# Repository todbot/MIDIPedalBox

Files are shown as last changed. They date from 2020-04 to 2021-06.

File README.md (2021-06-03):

# MIDIPedalBox

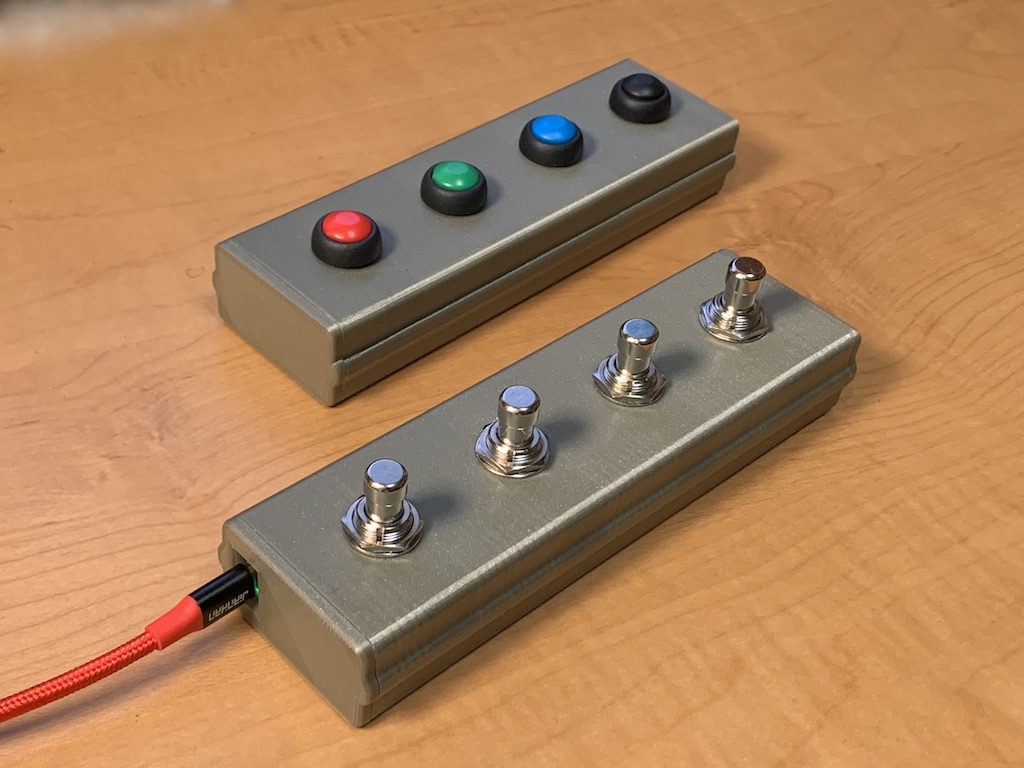
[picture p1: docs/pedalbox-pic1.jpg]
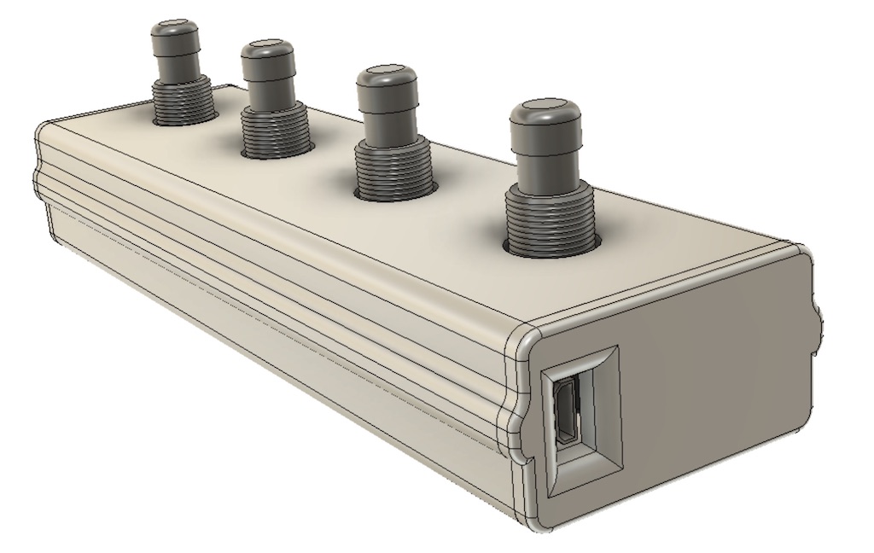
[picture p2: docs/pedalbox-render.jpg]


## Trinket M0 + CircuitPython USB MIDI Pedal Box

## Wiring  

The wiring is pretty straight-forward. A single wire goes from each button to pins 1,2,3,4 and a common ground connecting everybody.

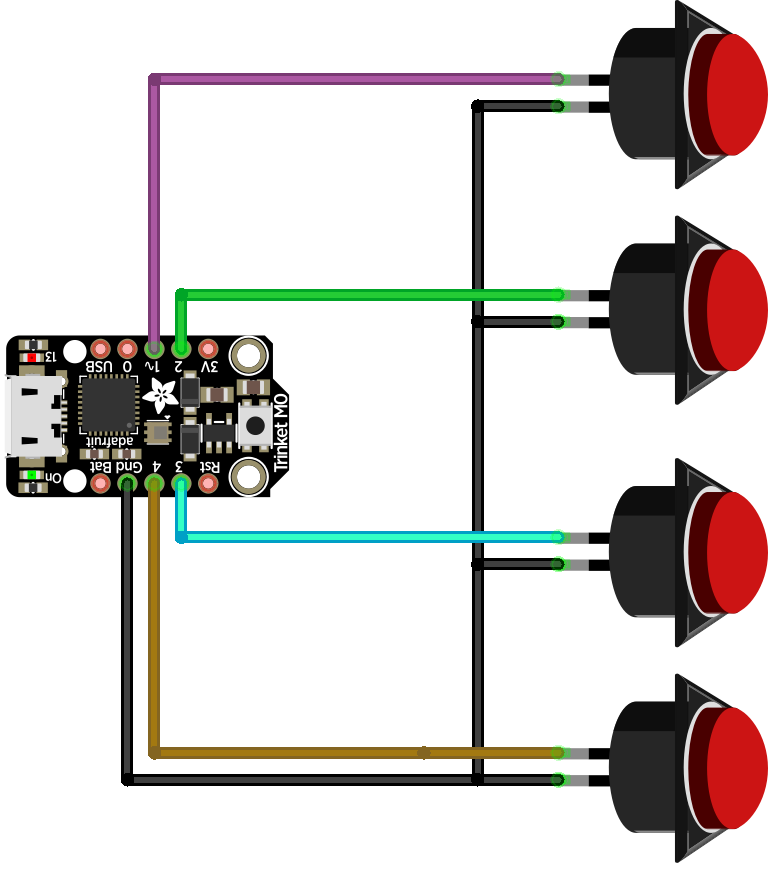
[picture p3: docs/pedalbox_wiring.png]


## Parts

The parts used for MIDIPedalBox:

- 1 - Adafruit Trinket M0
   - [Buy from Adafruit](https://www.adafruit.com/product/3500)
   - A [QT Py](https://www.adafruit.com/product/4600) or [Seeed XIAO](http://amzn.com/B08745JBRP?tag=todbotblog-20) will work too, with minor code modifications

- 4 - effects pedal switches
  - I chose these [generic momentary ones](http://amzn.com/B076V8C3LV?tag=todbotblog-20),
  but there are many to choose from and most all will work. Be sure to check dimensions to be sure!

or if you want push buttons instead of foot switches,

- 4 - 12 mm momentary buttons
  - I used [these from All Electronics](https://www.allelectronics.com/item/pb-138/spst-n.o.-pushbutton-red/1.html), but the equivalent are [available from Amazon](http://amzn.com/B07F24Y1TB?tag=todbotblog-20)

If you want to add serial MIDI out, the CAD includes a hole for a panel mount MIDI jack,
like [this one](http://amzn.com/B01GBT9RC0?tag=todbotblog-20)

_(Note: all Amazon links are affiliate links)_

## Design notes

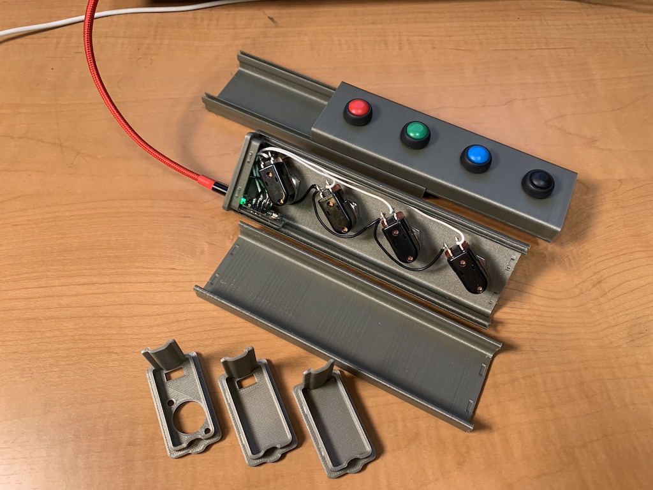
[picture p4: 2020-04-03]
docs/pedalbox-pic2.jpg

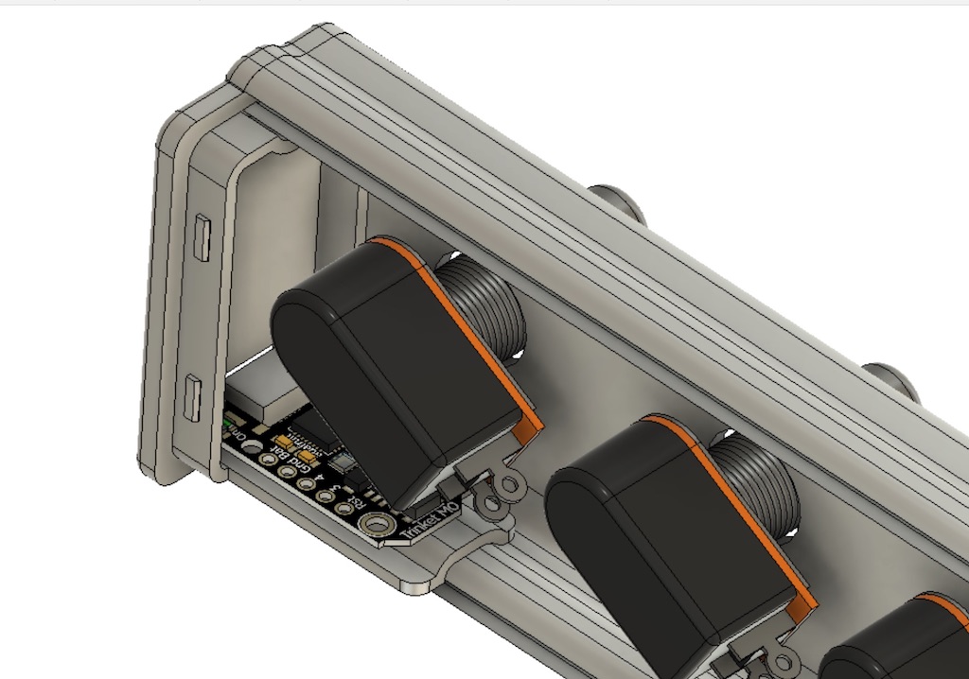
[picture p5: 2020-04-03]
docs/pedalbox-insides-render.jpg

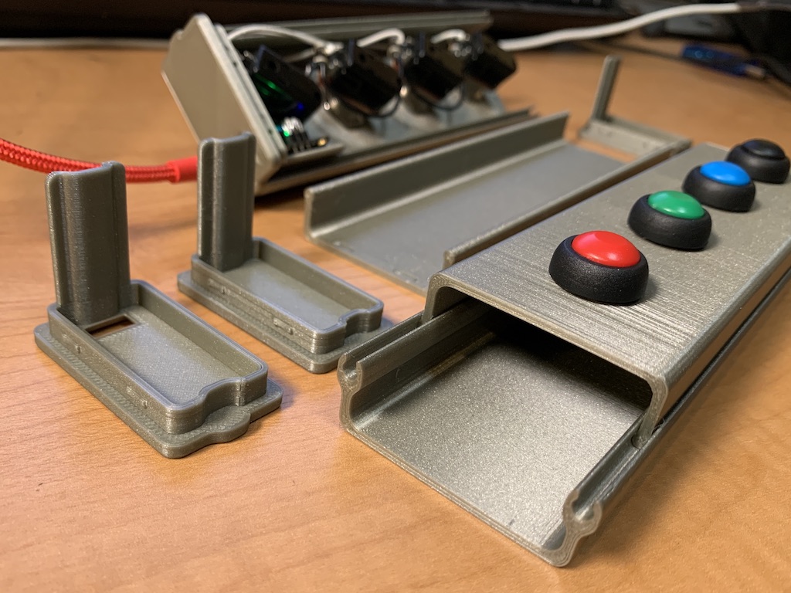
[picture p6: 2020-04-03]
docs/pedalbox-pic3.jpg

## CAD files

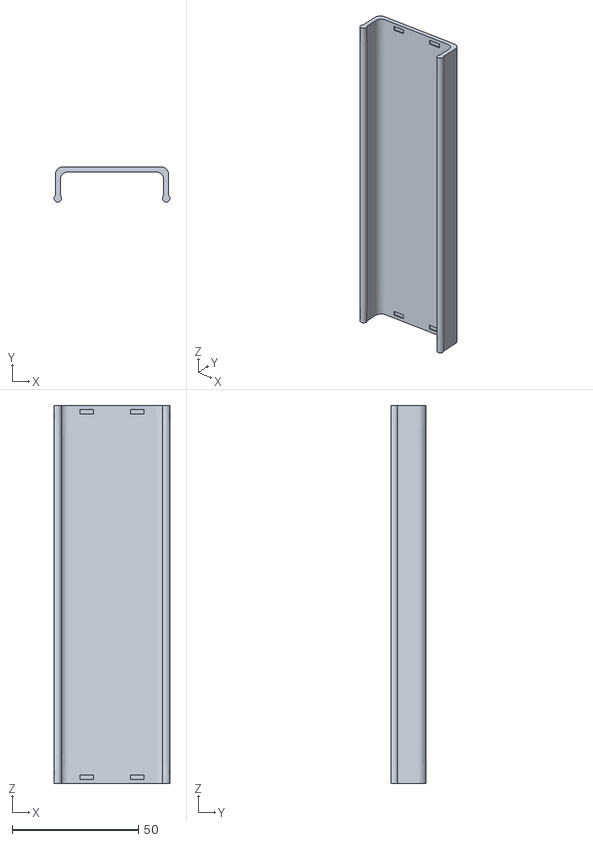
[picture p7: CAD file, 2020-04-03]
case/pedalbox-mainbot.stl
46.0 x 14.0 x 150.0

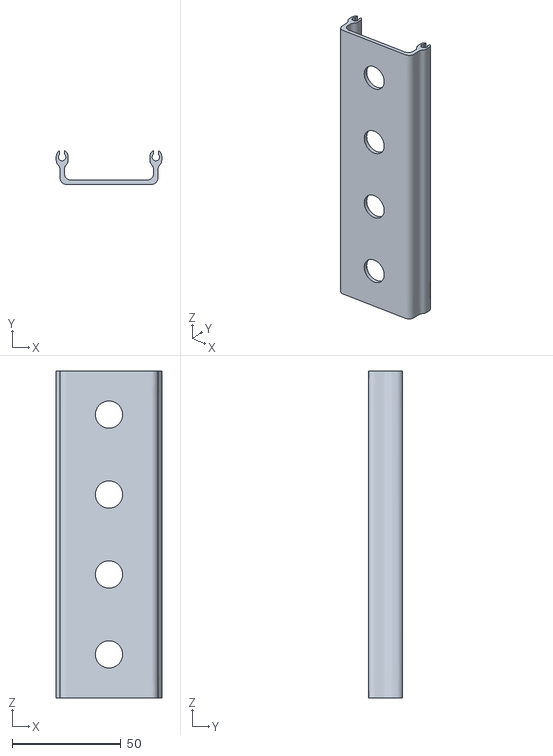
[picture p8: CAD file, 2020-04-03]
case/pedalbox-maintop.stl
48.4 x 15.5 x 150.0

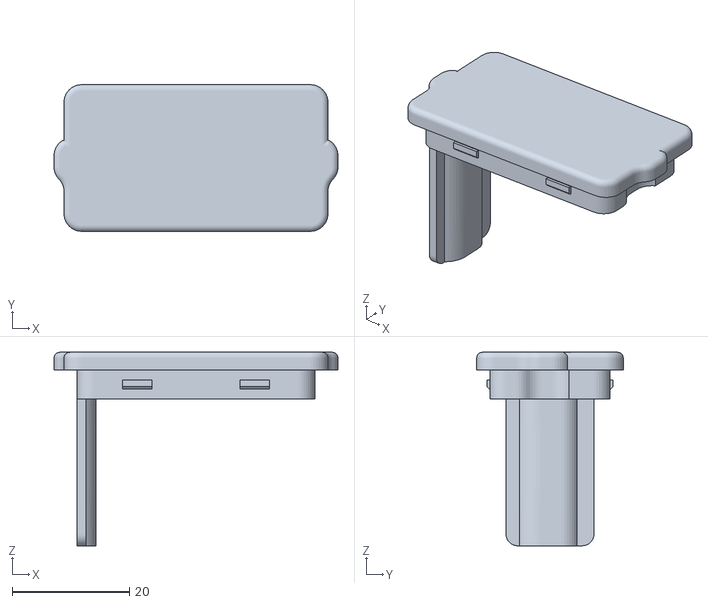
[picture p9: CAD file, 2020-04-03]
case/pedalbox-endcap_blank.stl
48.4 x 25.0 x 33.0

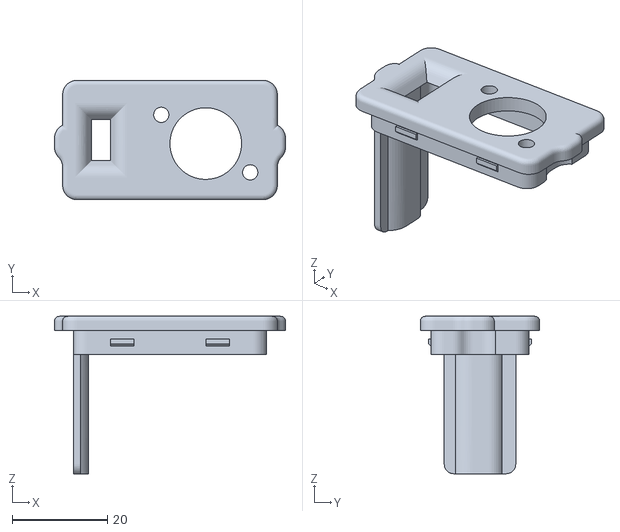
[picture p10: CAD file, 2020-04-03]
case/pedalbox-endcap_ midi.stl
48.4 x 25.0 x 33.0

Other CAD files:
case/pdealbox-endcap.stl
case/pedalbox.f3d

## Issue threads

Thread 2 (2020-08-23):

softreboot with pedalbox_keyboard.py

ericklein, 2020-08-23:
I logged an issue at https://github.com/adafruit/Adafruit_CircuitPython_Debouncer/issues/21 but wondering if you are seeing the same issue? I modified your code for debug and saw the same soft reboot I reported above after X loops with no button input.

I can remove the LED code with no change in output.
```
import time
import board
from digitalio import DigitalInOut, Direction, Pull
# import digitalio #adafruit version
# from analogio import AnalogOut, AnalogIn  #why do we need it?

import usb_hid
from adafruit_hid.keyboard import Keyboard
from adafruit_hid.keycode import Keycode
from adafruit_debouncer import Debouncer

print("imports ok")

# Your config!
# Set this to be which pins you're using, and what to do.
# For list of keycodes, see:
# https://circuitpython.readthedocs.io/projects/hid/en/latest/api.html
button_config = [
        # pin,     (Keycodes and modifier keycodes)
        [board.A1, (Keycode.SPACEBAR,) ],  # just a space
]
debouncers = []

#        [board.D2, (Keycode.A, Keycode.SHIFT, Keycode.GUI) ],# zoom mute
#        [board.D3, (Keycode.C, Keycode.CONTROL) ],
#        [board.D4, (Keycode.H, Keycode.GUI) ], # CMD-H hide

# start up the keyboardy-ness
time.sleep(1)  # Sleep for a bit to avoid a race condition on some systems
kbd = Keyboard(usb_hid.devices)

print("keyboard init ok")

# Built in red LED
led = DigitalInOut(board.D13)
led.direction = Direction.OUTPUT
button_light = DigitalInOut(board.D7)
button_light.direction = Direction.OUTPUT

print("LED setup ok")

# set up the pins and the debouncer on each pin
for (pin,*rest) in button_config:
        button = DigitalInOut(pin)
        button.direction = Direction.INPUT
        button.pull = Pull.UP
        debouncers.append( Debouncer(button) )

print("ready for main loop")

######################### MAIN LOOP ##############################
def main():
    while True:
        for i in range(len(button_config)):
            button = debouncers[i]
            button.update()

            (pin,keycodes) = button_config[i]
            print("button",i,"ready")
            if button.fell:
                print("push:",pin,"keycodes:",keycodes)
                #kbd.send(Keycode.SHIFT,Keycode.A)
                kbd.press(*keycodes)
                led.value = True
                button_light.value = True

            if button.rose:
                print("release:",pin)
                kbd.release(*keycodes)
                led.value = False
                button_light.value = False

            time.sleep(0.01)
######

# actually call main
main()
```

todbot, 2020-08-23:
interesting! I have not seen that but I've not gotten back to this project since I initially made it and I'm not sure I ever even had it running that long!

ericklein, 2020-08-23:
If you want to close this I can always open a new issue if I indeed find something.

todbot, 2020-08-24:
so I'm not seeing this on a Trinket M0 or an ItsyBitsy M4 running the `debouncer_simpletest.py`

Do you perhaps have an editor (like Mu) or other program that auto-scans serial ports, causing your board to disconnect/reconnect?

ericklein, 2020-08-24:
I’m slowly learning CP and just read that Mu can cause issues. Back to exclusive Sublime Text :) thanks for checking!

Sent via Superhuman iOS ( https://sprh.mn/?vip=me@ericklein.com )

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

Closed 2020-08-23.

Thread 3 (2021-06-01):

Recommended switches

gmeader, 2021-06-01:
What foot switch switches do you use?
Source?
Put that info in the README?

todbot, 2021-06-02:
All foot switches are pretty identical (to my non-guitarist eye), with the only real difference being momentary vs push-on/push-off.  The specific ones I purchased were these I think: https://www.amazon.com/Etopars-Guitar-Effects-Momentary-Button/dp/B076V8C3LV/

You are correct, I should add a BOM to the README. Thanks!

todbot, 2021-06-03:
thanks again!

Closed 2021-06-03.

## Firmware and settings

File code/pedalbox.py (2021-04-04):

# MIDIPedalBox -- USB and Classic MIDI output on a Trinket M0
#
# 2020-2021 @todbot / Tod E. Kurt
#
# To use:
#  - Copy this file as `code.py` in your Trinket's CIRCUITPY drive
#  - Install necessary extra libraries (see below)
#
# Extra modules needed:
# - adafruit_dotstar
# - adafruit_midi (but only "__init.mpy", "node_on.mpy", "note_off.mpy")
# - adafruit_debouncer
#
# These libraries can be installed all at once with:
#  circup install circup install adafruit_dotstar adafruit_midi adafruit_debouncer
# Get `circup` with `pip3 install circup`
#
# Classic MIDI (5-pin DIN MIDI) is on pin D0 and can be wired up as shown in
# the diagrams here:
#  https://learn.adafruit.com/classic-midi-synth-control-with-trellis-m4/midi-connections
# Specifically I've had luck with the following wiring:
#  - Trinket Gnd    ----------------------> Ring of Type-B adapter   --> MIDI pin 2
#  - Trinket 3v3    --> 47 ohm resistor --> Tip of Type-B adapter    --> MIDI pin 4
#  - Trinket Pin D0 --> 47 ohm resistor --> Sleeve of Type-B adapter --> MIDI pin 5
#

import time
import board
import busio
from digitalio import DigitalInOut, Direction, Pull
from analogio import AnalogOut, AnalogIn
import adafruit_dotstar as dotstar

import usb_midi
import adafruit_midi
from adafruit_midi.note_off         import NoteOff
from adafruit_midi.note_on          import NoteOn
from adafruit_debouncer import Debouncer

# memory is tight on Trinket, so let's clean up before we start
import gc
gc.collect()

# Your config!
# Set this to be which pins you're using, and what to do
button_config = [
		# pin,     midi press msg, midi release msg
		[board.D1, NoteOn(44,120), NoteOff(44,120) ],
		[board.D2, NoteOn(46,120), NoteOff(46,120) ],
		[board.D3, NoteOn(48,120), NoteOff(48,120) ],
		[board.D4, NoteOn(50,120), NoteOff(50,120) ],
]
debouncers = [] 

midi = adafruit_midi.MIDI(midi_out=usb_midi.ports[1], out_channel=0)
uart = busio.UART(board.D0, baudrate=31250, timeout=0.001) # initialize UART 
classic_midi = adafruit_midi.MIDI(midi_out=uart )

# One pixel connected internally!
dot = dotstar.DotStar(board.APA102_SCK, board.APA102_MOSI, 1, brightness=0.2)

# Built in red LED
led = DigitalInOut(board.D13)
led.direction = Direction.OUTPUT

# set up the pins and the debouncer on each pin
for (pin,*rest) in button_config:
		button = DigitalInOut(pin)
		button.direction = Direction.INPUT
		button.pull = Pull.UP
		debouncers.append( Debouncer(button) )
   
######################### MAIN LOOP ##############################
def main():
    doti = 0 
    while True:
        for i in range(len(button_config)):
            button = debouncers[i]
            button.update()
            
            (pin,onPress,onRelease) = button_config[i]
            
            if button.fell:
                print("push:",pin)
                midi.send(onPress)
                classic_midi.send(onPress)
                
            if button.rose:
                print("release:",pin)
                midi.send(onRelease)
                classic_midi.send(onRelease)
                
        # spin internal LED around! autoshow is on
        dot[0] = wheel(doti & 255)
        doti = (doti+1) % 256  # run from 0 to 255

######################### HELPERS ##############################

# Helper to give us a nice color swirl
def wheel(pos):
    # Input a value 0 to 255 to get a color value.
    # The colours are a transition r - g - b - back to r.
    if (pos < 0):   return [0, 0, 0]
    if (pos > 255): return [0, 0, 0]
    if (pos < 85):  return [int(pos * 3), int(255 - (pos*3)), 0]
    elif (pos < 170):
        pos -= 85
        return [int(255 - pos*3), 0, int(pos*3)]
    else:
        pos -= 170
        return [0, int(pos*3), int(255 - pos*3)]

# actually call main
print("Hello MIDIPedalBox")
main()

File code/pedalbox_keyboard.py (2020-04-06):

# KeyboardPedalBox
#
# 2020 @todbot / Tod E. Kurt
#
# Extra modules needed:
# - adafruit_hid (but only "__init.mpy", "keyboard.mpy", "keycode.mpy")
# - adafruit_debouncer
#

import board
from digitalio import DigitalInOut, Direction, Pull
from analogio import AnalogOut, AnalogIn
import time

import usb_hid
from adafruit_hid.keyboard import Keyboard
from adafruit_hid.keycode import Keycode
from adafruit_debouncer import Debouncer

# Your config!
# Set this to be which pins you're using, and what to do. 
# For list of keycodes, see:
# https://circuitpython.readthedocs.io/projects/hid/en/latest/api.html
button_config = [
		# pin,     (Keycodes and modifier keycodes)
		[board.D1, (Keycode.SPACEBAR,) ], # just a space
		[board.D2, (Keycode.A, Keycode.SHIFT, Keycode.GUI) ],# zoom mute
		[board.D3, (Keycode.C, Keycode.CONTROL) ],
		[board.D4, (Keycode.H, Keycode.GUI) ], # CMD-H hide
]
debouncers = [] 

# start up the keyboardy-ness
time.sleep(1)  # Sleep for a bit to avoid a race condition on some systems
kbd = Keyboard(usb_hid.devices)

# Built in red LED
led = DigitalInOut(board.D13)
led.direction = Direction.OUTPUT

# set up the pins and the debouncer on each pin
for (pin,*rest) in button_config:
		button = DigitalInOut(pin)
		button.direction = Direction.INPUT
		button.pull = Pull.UP
		debouncers.append( Debouncer(button) )

print("Hello from KeyboardPedalBox")

######################### MAIN LOOP ##############################
def main():
    while True:
        for i in range(len(button_config)):
            button = debouncers[i]
            button.update()
            
            (pin,keycodes) = button_config[i]
            
            if button.fell:
                print("push:",pin,"keycodes:",keycodes)
                #kbd.send(Keycode.SHIFT,Keycode.A)
                kbd.press(*keycodes)
                
            if button.rose:
                print("release:",pin)
                kbd.release(*keycodes)
                

######

# actually call main
main()

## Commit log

2020-04-03 first checkin, added v53 f3d
    [pdealbox-endcap.stl, pedalbox-endcap_ midi.stl, pedalbox-endcap_blank.stl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]
2020-04-06 added wiring diagram
2021-04-03 added notes about classic midi wiring
2021-04-04 update classic DIN MIDI wiring
